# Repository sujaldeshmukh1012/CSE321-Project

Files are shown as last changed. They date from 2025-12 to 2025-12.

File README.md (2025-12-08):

<div id="top">

<!-- HEADER STYLE: CLASSIC -->
<div align="center">

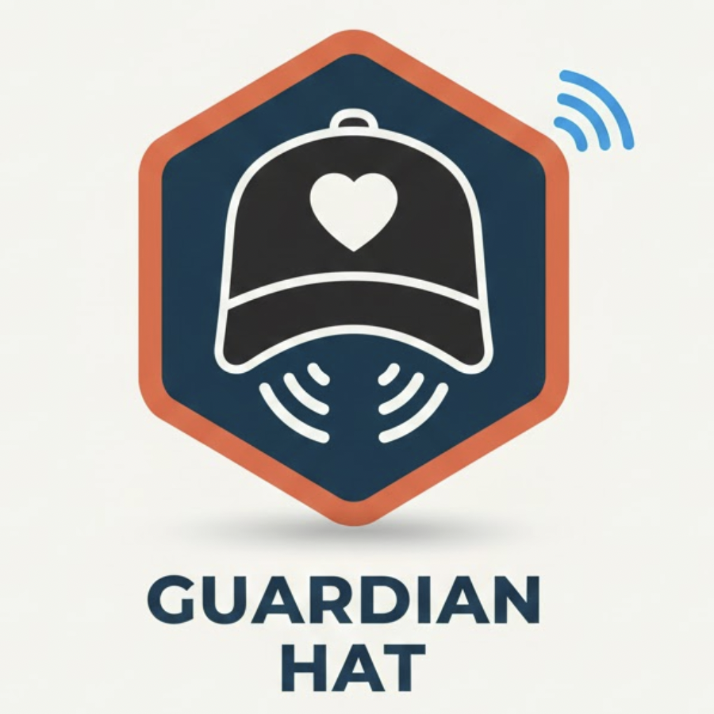
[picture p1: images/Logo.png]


# GuardianHAT

<em>Real-Time Embedded System for GPS Tracking and Environmental Monitoring</em>

<!-- BADGES -->






<em>Built with the tools and technologies:</em>

**C/C++ • ESP32-CAM • Arduino Nano • FreeRTOS • PlatformIO • KiCad PCB Design**

</div>
<br>

---

## Table of Contents

- [Overview](#overview)
- [Features](#features)
- [Hardware Components](#hardware-components)
- [PCB Design](#pcb-design)
  - [PCB Images](#pcb-images)
  - [Design Process](#design-process)
  - [Bill of Materials](#bill-of-materials)
- [Project Structure](#project-structure)
- [Getting Started](#getting-started)
  - [Prerequisites](#prerequisites)
  - [Installation](#installation)
  - [Usage](#usage)
  - [Testing](#testing)
- [System Architecture](#system-architecture)
- [Implimentation](#implimentation)
- [Contributing](#contributing)
- [License](#license)
- [Author](#author)
- [Acknowledgments](#acknowledgments)

---

## Overview

GuardianHAT is a comprehensive embedded systems solution that integrates GPS tracking, environmental sensing, and real-time monitoring capabilities. The project features two main components: an ESP32-CAM based system for camera functionality and location tracking, and an Arduino Nano RTOS implementation for sensor data processing with FreeRTOS task management.

The system includes a custom-designed PCB (Caretaker Board) that integrates all components for a professional, production-ready embedded solution.

**Key Highlights:**
- Real-time GPS satellite tracking and location monitoring
- Environmental sensing with MPU6050 (accelerometer/gyroscope)
- Distance measurement using VL53L0X ToF sensor
- OLED display (SSD1306) for real-time data visualization
- Custom PCB design with professional manufacturing files
- Multi-threaded RTOS implementation for concurrent task execution

---

## Features

### Core Functionality
- **GPS Tracking**: Real-time satellite position tracking with TinyGPS++ library
- **Motion Detection**: 6-axis motion sensing using MPU6050 (accelerometer + gyroscope)
- **Distance Measurement**: Precise ranging with VL53L0X Time-of-Flight sensor
- **Visual Display**: 128x64 OLED display for live sensor data and status information
- **Camera Module**: ESP32-CAM integration for image capture and processing
- **Real-Time OS**: FreeRTOS implementation for efficient task scheduling and resource management

### Technical Features
- Multi-tasking architecture with independent sensor polling tasks
- I2C and SPI communication protocols
- Low-power design optimizations
- Interrupt-driven button and buzzer control
- Hardware abstraction for easy sensor integration
- Professional PCB with proper power regulation and signal integrity

---

## Hardware Components

| Component | Model | Interface | Purpose |
|---|---|---|---|
| **Microcontroller** | ESP32-S3 (CAM) | - | Main processing unit with WiFi/BT |
| **Microcontroller** | Arduino Nano Every | - | RTOS sensor controller |
| **GPS Module** | NEO-6M | UART | Location tracking |
| **IMU Sensor** | MPU6050 | I2C | Motion and orientation |
| **Distance Sensor** | VL53L0X | I2C | Time-of-Flight ranging |
| **Display** | SSD1306 OLED | I2C | 128x64 visual feedback |
| **Camera** | OV2640 | - | Image capture |
| **Feedback** | Buzzer, LED| GPIO| User feedback|
| **Actuators** | Servos | PWM | Control |

---

## PCB Design

### PCB Images

The custom Caretaker PCB was designed in KiCad to integrate all system components on a single board.

<div style="display:flex;align-items:center;justify-content:space-between;" > 
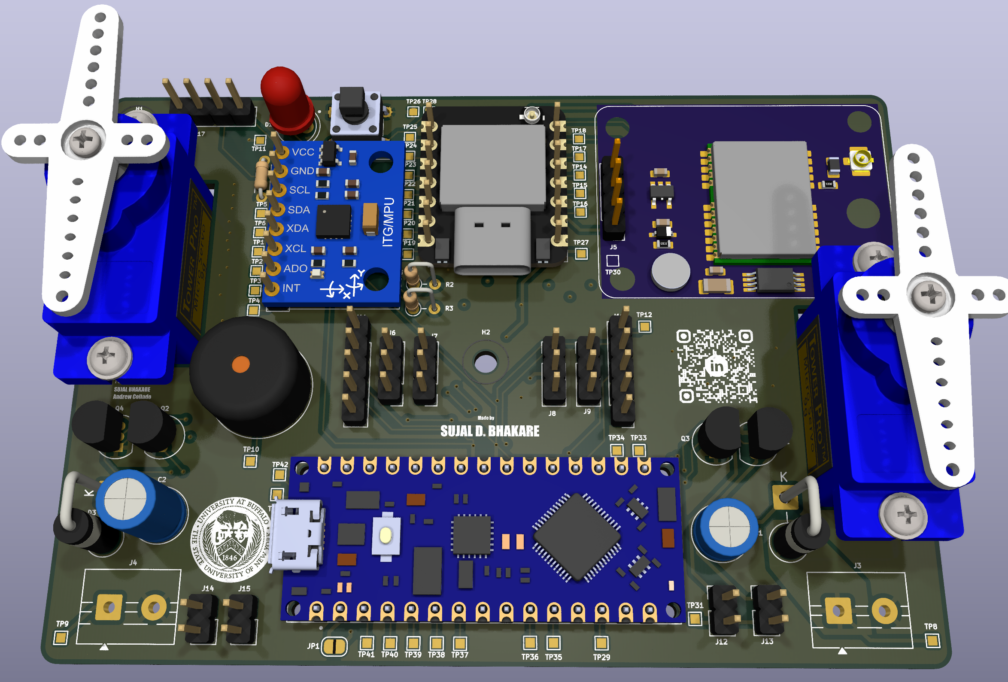
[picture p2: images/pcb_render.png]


</div>
<div style="display:flex;align-items:center;justify-content:space-between;" > 
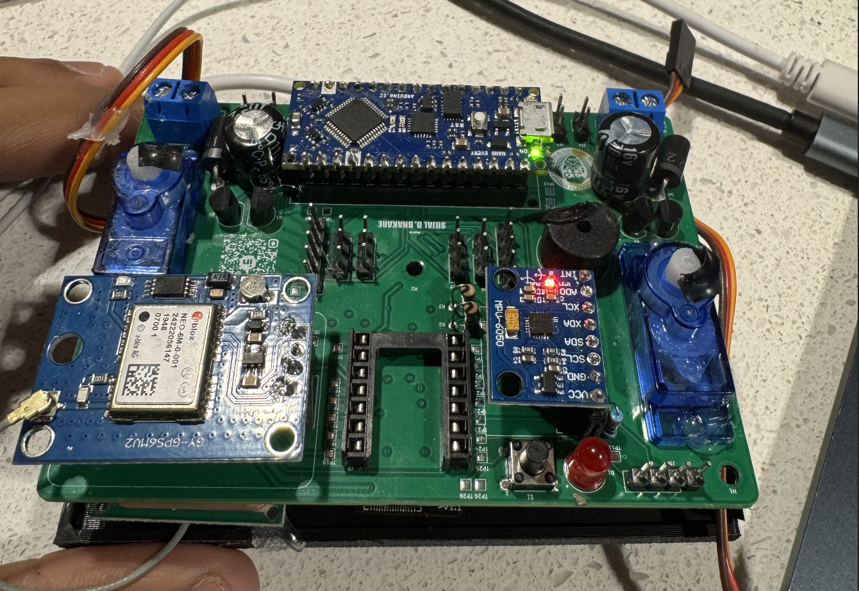
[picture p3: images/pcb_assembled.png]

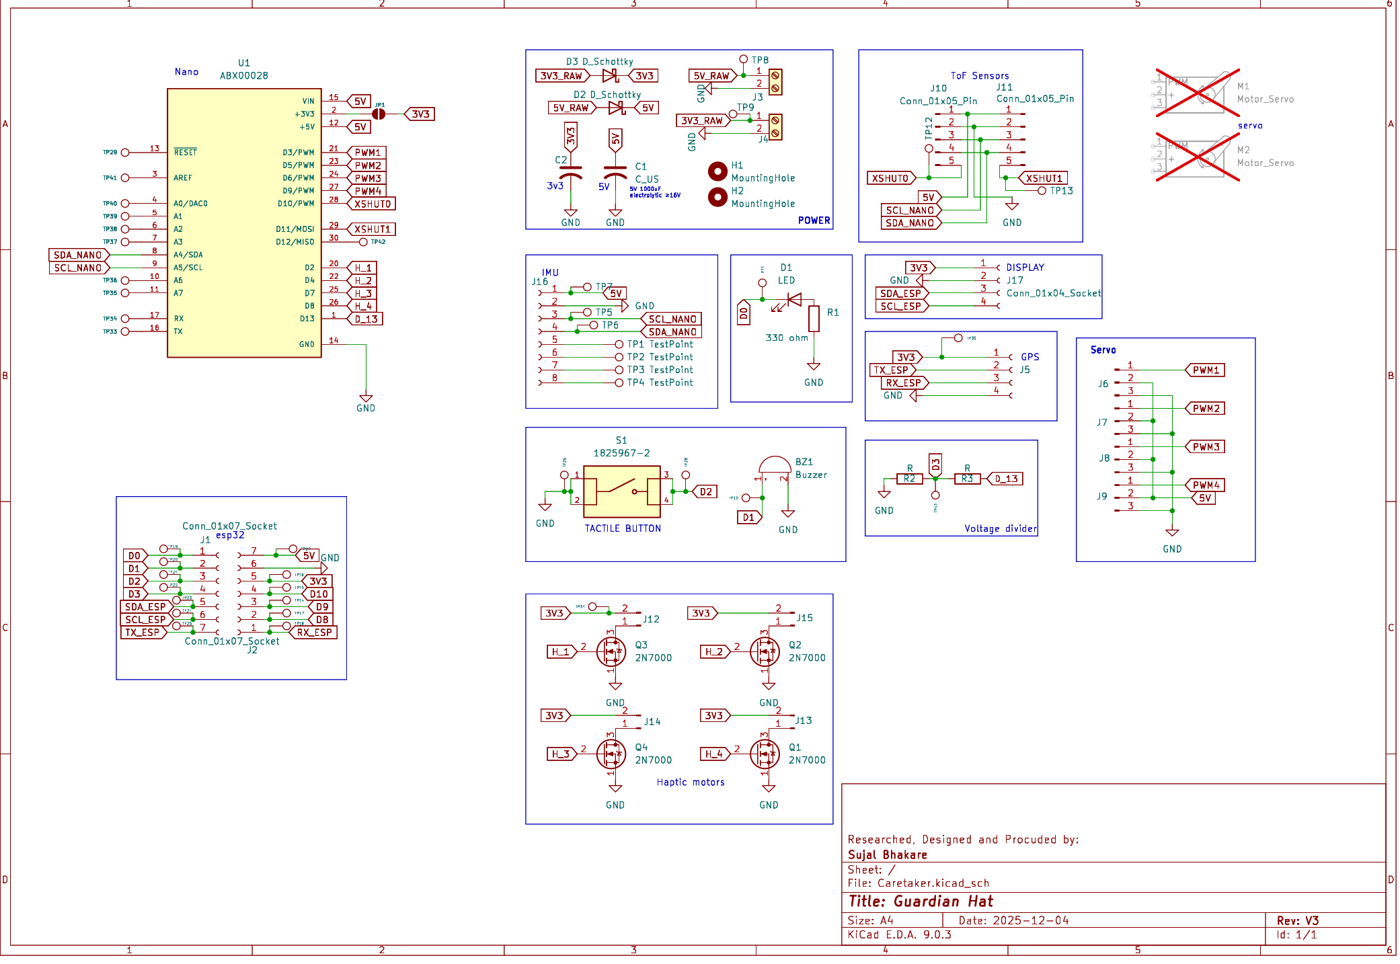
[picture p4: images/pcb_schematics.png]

</div>

### Design Process

**Tools Used:**
- **KiCad 6.0+**: Schematic capture and PCB layout
- **Component Libraries**: Custom footprints for Adafruit modules and sensors

**Manufacturing Files** (Generated Gerbers):
- `Caretaker-F_Cu.gbr` - Front copper layer
- `Caretaker-B_Cu.gbr` - Back copper layer
- `Caretaker-F_Mask.gbr` - Front soldermask
- `Caretaker-B_Mask.gbr` - Back soldermask
- `Caretaker-F_Paste.gbr` - Front paste layer (for stencil)
- `Caretaker-B_Paste.gbr` - Back paste layer
- `Caretaker-F_Silkscreen.gbr` - Front silkscreen
- `Caretaker-B_Silkscreen.gbr` - Back silkscreen
- `Caretaker-Edge_Cuts.gbr` - Board outline
- `Caretaker-job.gbrjob` - Gerber job file

**PCB Specifications:**
- **Layers**: 2-layer PCB
- **Dimensions**: 99mm x 70mm
- **Thickness**: 1.6mm (standard)
- **Copper Weight**: 1 oz (35 μm)
- **Surface Finish**: HASL

**Design Considerations:**
- Proper power plane separation for analog/digital circuits
- I2C pull-up resistors on SDA/SCL lines
- Decoupling capacitors near power pins
- Ground plane for noise reduction
- Clear component labeling on silkscreen

### Bill of Materials

Complete the quantities and part numbers based on your actual design:

| Qty | Value | Package | Description | Manufacturer Part # | Notes |
|-----|---|---|---|---|---|
| 1  | ESP32-S3 | Module | Main MCU with WiFi/BT | ESP32-S3-WROOM-1 | Seeed XIAO ESP32S3 |
| 1  | Arduino Nano | Module | RTOS Controller | ABX00028 | Arduino Nano Every |
| 1  | NEO-6M | Module | GPS Module | NEO-6M | U-blox GPS |
| 1  | MPU6050 | Module | 6-axis IMU | GY-521 | Accelerometer + Gyro |
| 1  | VL53L0X | Module | ToF Distance Sensor | - | Adafruit breakout |
| 1  | SSD1306 | Module | OLED Display | - | 128x64 I2C display |
| 1  | OV2640 | Module | Camera Module | - | ESP32-CAM compatible |
| 4  | Servo | SG90 | Micro Servo 9g | SG90 | Tower Pro |
| 1  | Buzzer | THT | Active/Passive Buzzer | - | 5V buzzer |
| 2 | LED | THT | Status Indicators | - | Red/Green |
| 2 | Resistor 4.7kΩ | THT | I2C Pull-up Resistors | - | 1% tolerance |
| 4 | Resistor 330Ω | THT | LED Current Limiting | - | - |
| 1 | Push Button | THT | User Input | 1825967-2 | Tactile switch |
| 4 | Capacitor 0.1µF | THT | Decoupling Capacitors | - | Ceramic, X7R |
| 2 | Capacitor 470µF | THT | Bulk Capacitors | - | Ceramic, X7R |
| 1 | Header | 2.54mm | UART/Debug | - | 4-pin header |
| 3 | Header | 2.54mm | I2C Expansion | - | 4-pin headers |

**Total Estimated Cost**: $50.00

**Suggested Suppliers:**
- DigiKey
- Mouser Electronics  
- Adafruit
- SparkFun
- Amazon (for modules)
- JLCPCB (for pcb fabrication)

---

## Project Structure

```sh
└── GuardianHAT/
    ├── ESP32_CAM/                    # ESP32-CAM module firmware
    │   ├── platformio.ini            # PlatformIO configuration
    │   ├── src/
    │   │   └── main.cpp              # Main ESP32 application
    │   ├── testing_code/             # Individual component tests
    │   │   ├── GPS.cpp               # GPS module testing
    │   │   ├── display.cpp           # OLED display testing
    │   │   └── buzzer_button_led.cpp # I/O peripheral tests
    │   └── lib/                      # External libraries
    │
    ├── NANO_RTOS/                    # Arduino Nano with FreeRTOS
    │   ├── platformio.ini            # PlatformIO configuration
    │   ├── src/
    │   │   └── main.cpp              # FreeRTOS task implementation
    │   └── lib/                      # RTOS and sensor libraries
    │
    ├── PCB_Design/                   # KiCad PCB project
    │   ├── Caretaker.kicad_pro       # KiCad project file
    │   ├── Caretaker.kicad_sch       # Schematic file
    │   ├── Caretaker.kicad_pcb       # PCB layout file
    │   ├── Library/                  # Custom component libraries
    │   │   ├── symbols/              # Custom schematic symbols
    │   │   └── footprints/           # Custom PCB footprints
    │   ├── Production/               # Manufacturing files (Gerbers)
    │      └── *.gbr                 # Gerber files for fab house
    │
    ├── LICENSE                       # Project license
    └── README.md                     # This file
```

---

## Getting Started

### Prerequisites

**Software Requirements:**
- **PlatformIO**: IDE extension for VS Code or CLI
- **Python 3.7+**: For PlatformIO installation
- **Git**: For version control
- **KiCad 7.0+**: For PCB design viewing/editing (optional)

**Hardware Requirements:**
- ESP32-S3 development board (Seeed XIAO ESP32S3 or similar)
- Arduino Nano Every
- USB-C cable for ESP32
- Micro-USB cable for Arduino Nano
- All sensors and components from BOM

### Installation

1. **Clone the repository:**

```sh
git clone https://github.com/sujaldeshmukh1012/GuardianHAT.git
cd GuardianHAT
```

2. **Install PlatformIO:**

```sh
# Install PlatformIO Core (CLI)
pip install platformio

# Or install VS Code + PlatformIO IDE extension
code --install-extension platformio.platformio-ide
```

3. **Install project dependencies:**

PlatformIO will automatically install dependencies defined in `platformio.ini` when you build the project.

```sh
# For ESP32-CAM module
cd ESP32_CAM
pio lib install

# For NANO RTOS module
cd ../NANO_RTOS
pio lib install
```

### Usage

**Build and Upload ESP32-CAM Firmware:**

```sh
cd ESP32_CAM
pio run --target upload
pio device monitor  # View serial output
```

**Build and Upload Arduino Nano Firmware:**

```sh
cd NANO_RTOS
pio run --target upload
pio device monitor  # View serial output
```

**Serial Monitor Settings:**
- Baud Rate: 115200
- Line Ending: Newline

**Expected Output:**
```
[GPS] Satellites: 8, Location: 42.9634° N, 78.7384° W
[MPU6050] Accel: X=0.02g Y=0.98g Z=0.05g
[VL53L0X] Distance: 245mm
[Display] Status: OK
```

### Testing

The project includes individual component test files in `ESP32_CAM/testing_code/`:

**Test GPS Module:**
```sh
# Edit platformio.ini to set src_dir to testing_code
# Then uncomment the GPS.cpp file
pio run --target upload
```

**Test Display:**
```sh
# Use display.cpp as main source
pio run --target upload
```

**Test I/O Peripherals:**
```sh
# Use buzzer_button_led.cpp as main source
pio run --target upload
```

**Run All Tests:**
```sh
# Both projects include test directories
cd NANO_RTOS
pio test

cd ../ESP32_CAM
pio test
```

---

## System Architecture

### ESP32-CAM Module
- **Main Tasks**: Camera capture, WiFi connectivity, GPS data logging
- **Sensors**: GPS (NEO-6M), Camera (OV2640)
- **Communication**: WiFi for data transmission

### Arduino Nano RTOS Module
- **Main Tasks**: Sensor polling, OLED display updates, real-time processing
- **RTOS Tasks**:
  - Task 1: MPU6050 data acquisition (100Hz)
  - Task 2: VL53L0X distance measurement (50Hz)
  - Task 3: Display update task (10Hz)
  - Task 4: User input handling (interrupt-based)
- **Communication**: I2C for sensors, SPI for potential expansions

### Communication Protocol
The two modules communicate via UART to share sensor data and coordinate actions.

---
## Implimentation

The project was designed and demoed for the CSE 321 class project at University at Buffalo.

I have used external power and step-down converters to provide ample power to the 5v and 3v3 systems.

**The class has a constraint to use from the shelf Arduino products like Nano, Uno, Mega. So the project used the full dev boards instead of a much compact custom board using only what is needed.**

<div style="display:flex;align-items:center;justify-content:space-between;" > 
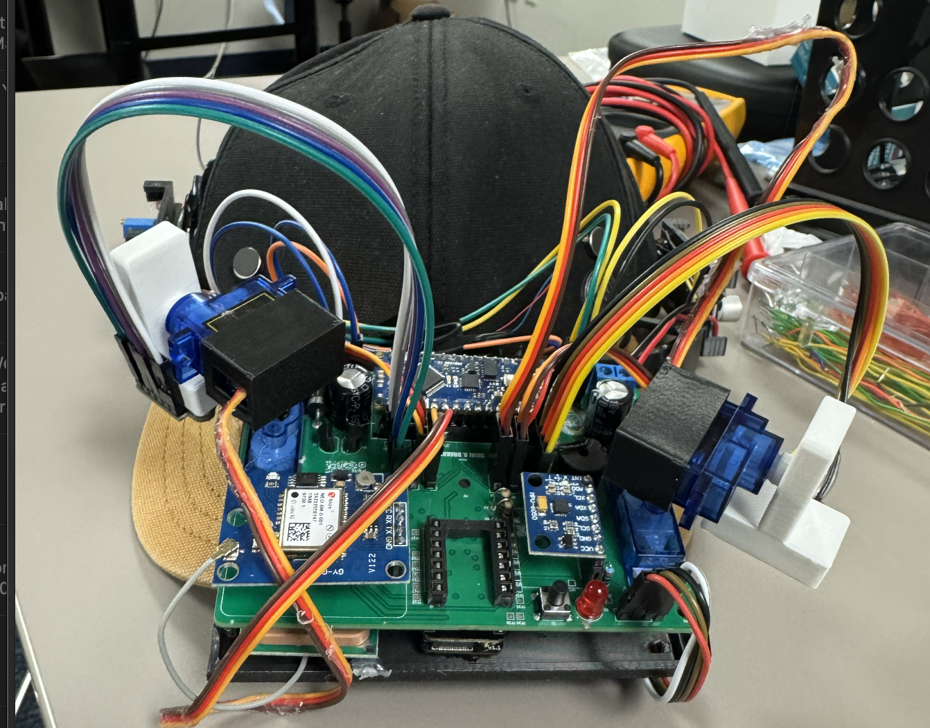
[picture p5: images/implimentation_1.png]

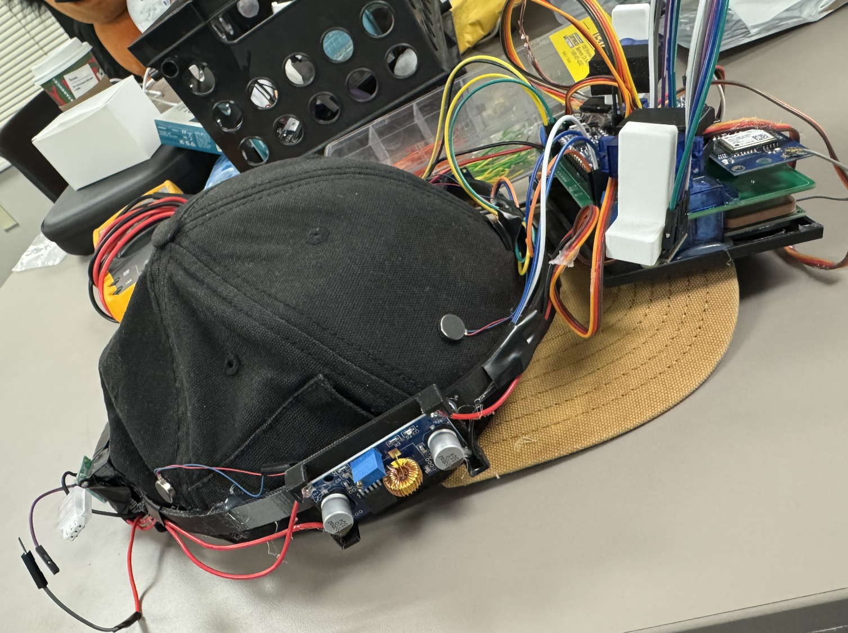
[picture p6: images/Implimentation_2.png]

</div>

<br>
<div style="display:flex;align-items:center;justify-content:center;">
  <a href="https://www.youtube.com/shorts/iIOURSS3Xgc" style="text-decoration:none;">
      
  </a>
</div>

---

## Author

<div align="center">

Your Name

### Sujal Bhakare

**Systems Engineer | Computer Science Student**






</div>
---

## Acknowledgments

- **Adafruit Industries**: For excellent sensor libraries and breakout boards
- **Arduino Community**: For FreeRTOS port and examples
- **Espressif Systems**: For ESP32 development framework
- **KiCad EDA**: For open-source PCB design software
- **TinyGPS++**: Mikal Hart's GPS parsing library
- **Course Staff**: CSE321 instructor and TAs
- **My Amazing Teammate:** Andrew Collado [LinkedIn](https://www.linkedin.com/in/andrew-collado/)

### References
- [ESP32-CAM Documentation](https://docs.espressif.com/)
- [FreeRTOS Documentation](https://www.freertos.org/Documentation/RTOS_book.html)
- [KiCad Documentation](https://docs.kicad.org/)
- [PlatformIO Documentation](https://docs.platformio.org/)

---

<div align="center">

**[⬆ Back to Top](#top)**

Made with ❤️ by [Andrew Collado]((https://www.linkedin.com/in/andrew-collado/)) & [Sujal Bhakare](https://sujalbhakare.com)

</div>

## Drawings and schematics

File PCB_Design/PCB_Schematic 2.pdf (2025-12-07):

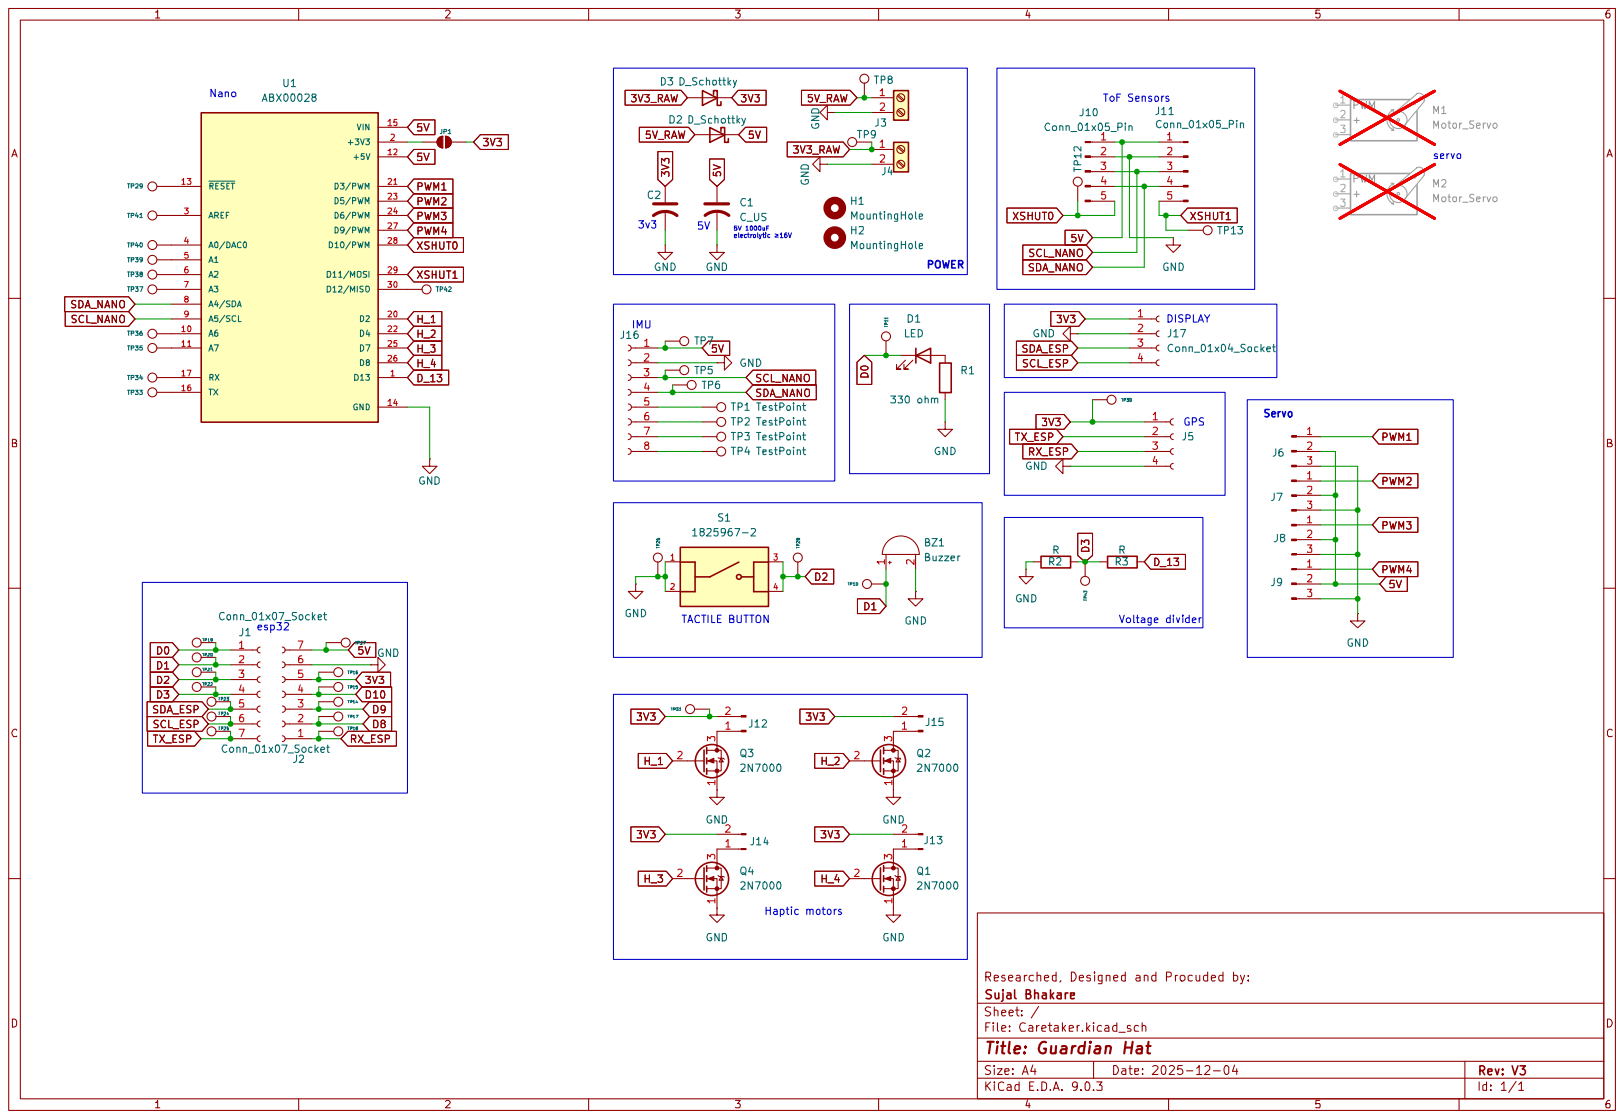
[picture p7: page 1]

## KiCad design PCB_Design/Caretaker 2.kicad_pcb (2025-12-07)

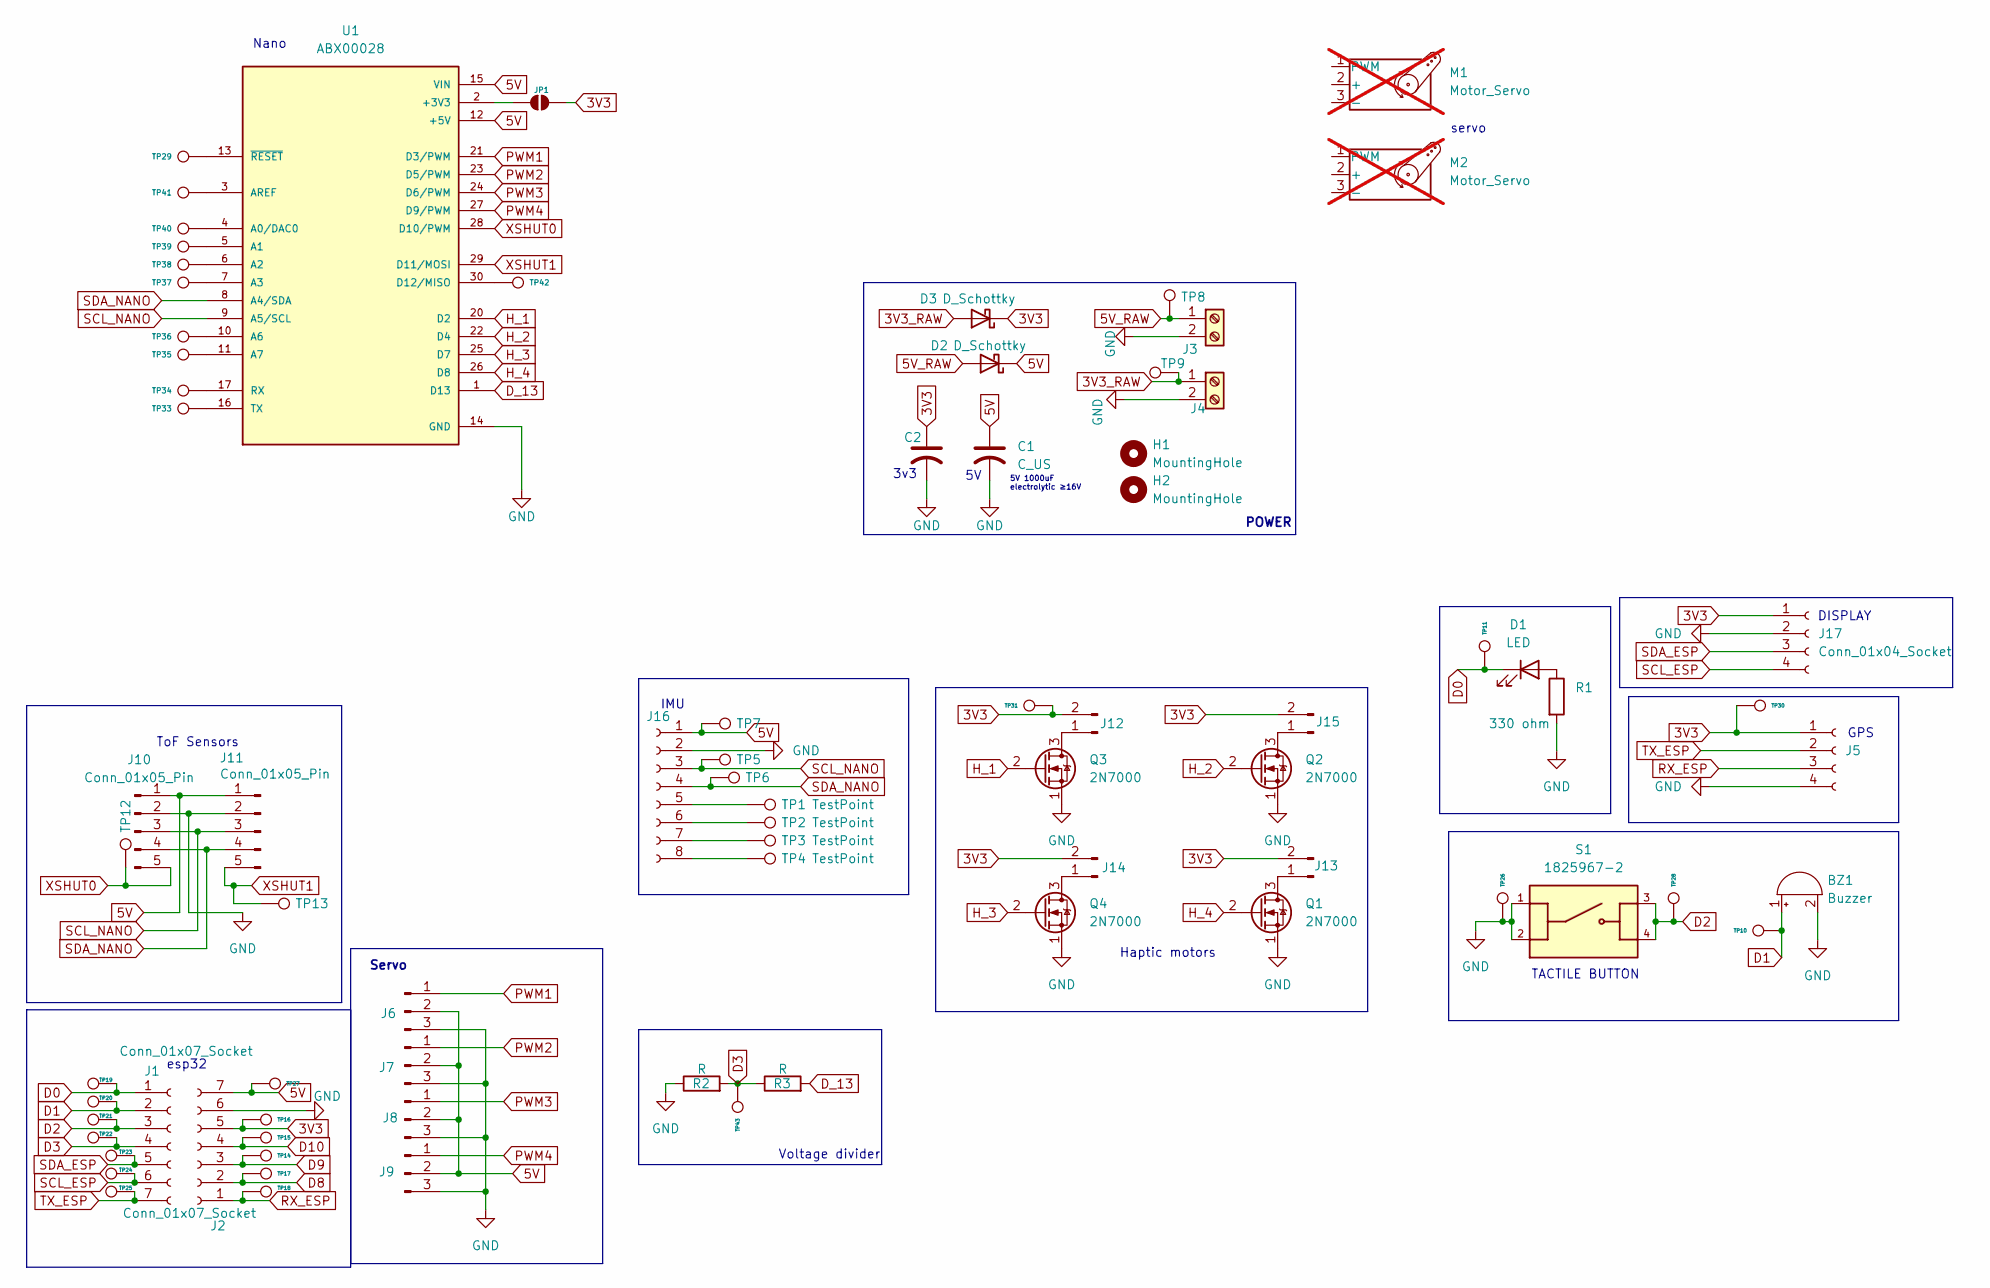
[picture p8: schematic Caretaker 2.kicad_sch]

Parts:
BZ1: Buzzer; Buzzer_12x9.5RM7.6
C1: C_US; C_Radial_D6.3mm_H5.0mm_P2.50mm
C2: C_US; C_Radial_D6.3mm_H11.0mm_P2.50mm
D1: LED; LED_D5.0mm
D2, D3: D_Schottky; D_5W_P5.08mm_Vertical_KathodeUp
H1, H2: MountingHole; MountingHole_2.7mm_M2.5
J1, J2: Conn_01x07_Socket; PinHeader_1x07_P2.54mm_Vertical
J3, J4: Screw_Terminal_01x02; TerminalBlock_MaiXu_MX126-5.0-02P_1x02_P5.00mm
J5, J17: Conn_01x04_Socket; PinHeader_1x04_P2.54mm_Vertical
J6, J7, J8, J9: Conn_01x03_Pin; PinHeader_1x03_P2.54mm_Vertical
J10, J11: Conn_01x05_Pin; PinHeader_1x05_P2.54mm_Vertical
J12, J13, J14, J15: Conn_01x02_Pin; PinHeader_1x02_P2.54mm_Vertical
J16: Conn_01x08_Socket; PinHeader_1x08_P2.54mm_Vertical
JP1: SolderJumper_2_Open; SolderJumper-2_P1.3mm_Open_RoundedPad1.0x1.5mm
M1, M2: Motor_Servo; MountingHole_8.4mm_M8_Pad_TopOnly; not fitted
Q1, Q2, Q3, Q4: 2N7000; TO-92_Inline
R1: 330 ohm; R_Axial_DIN0204_L3.6mm_D1.6mm_P5.08mm_Horizontal
R2, R3: R; R_Axial_DIN0204_L3.6mm_D1.6mm_P2.54mm_Vertical
S1: 1825967-2; SW_1825967-2
TP1, TP2, TP3, TP4, TP5, TP6, TP7, TP8, TP9, TP10, TP11, TP12, TP13, TP14, TP15, TP16, TP17, TP18, TP19, TP20, TP21, TP22, TP23, TP24, TP25, TP26, TP27, TP28, TP29, TP30, TP31, TP33, TP34, TP35, TP36, TP37, TP38, TP39, TP40, TP41, TP42, TP43: TestPoint; TestPoint_Pad_1.0x1.0mm
U1: ABX00028; MODULE_ABX00028; PARTREV 6-11-19

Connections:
3V3: C2.1, D3.1 (K), J2.5, J5.1, J12.2, J13.2, J14.2, J15.2, J17.1, JP1.2 (B), TP16.1, TP30.1, TP31.1
3V3_RAW: D3.2 (A), J4.1, TP9.1
5V: C1.1, D2.1 (K), J2.7, J6.2, J7.2, J8.2, J9.2, J10.1, J11.1, J16.1, TP7.1, TP27.1, U1.12 (+5V), U1.15 (VIN)
5V_RAW: D2.2 (A), J3.1, TP8.1
D0: D1.1 (K), J1.1, TP11.1, TP19.1
D1: BZ1.1 (+), J1.2, TP10.1, TP20.1
D2: J1.3, S1.3, S1.4, TP21.1, TP28.1
D3: J1.4, R2.2, R3.1, TP22.1, TP43.1
D8: J2.2, TP17.1
D9: J2.3, TP14.1
D10: J2.4, TP15.1
D_13: R3.2, U1.1 (D13)
GND: BZ1.2 (-), C1.2, C2.2, J2.6, J3.2, J4.2, J5.4, J6.3, J7.3, J8.3, J9.3, J10.2, J11.2, J16.2, J17.2, Q1.1 (S), Q2.1 (S), Q3.1 (S), Q4.1 (S), R1.2, R2.1, S1.1, S1.2, TP26.1, U1.14 (GND), U1.19 (GND)
H_1: Q3.2 (G), U1.20 (D2)
H_2: Q2.2 (G), U1.22 (D4)
H_3: Q4.2 (G), U1.25 (D7)
H_4: Q1.2 (G), U1.26 (D8)
unnamed: D1.2 (A), R1.1
unnamed: J12.1, Q3.3 (D)
unnamed: J13.1, Q1.3 (D)
unnamed: J14.1, Q4.3 (D)
unnamed: J15.1, Q2.3 (D)
unnamed: J16.5, TP1.1
unnamed: J16.6, TP2.1
unnamed: J16.7, TP3.1
unnamed: J16.8, TP4.1
unnamed: JP1.1 (A), U1.2 (+3V3)
unnamed: TP29.1, U1.13 (~RESET), U1.18 (~RESET)
unnamed: TP40.1, U1.4 (A0/DAC0)
unnamed: TP39.1, U1.5 (A1)
unnamed: TP38.1, U1.6 (A2)
unnamed: TP37.1, U1.7 (A3)
unnamed: TP36.1, U1.10 (A6)
unnamed: TP35.1, U1.11 (A7)
unnamed: TP41.1, U1.3 (AREF)
unnamed: TP42.1, U1.30 (D12/MISO)
unnamed: TP34.1, U1.17 (RX)
unnamed: TP33.1, U1.16 (TX)
PWM1: J6.1, U1.21 (D3/PWM)
PWM2: J7.1, U1.23 (D5/PWM)
PWM3: J8.1, U1.24 (D6/PWM)
PWM4: J9.1, U1.27 (D9/PWM)
RX_ESP: J2.1, J5.3, TP18.1
SCL_ESP: J1.6, J17.4, TP24.1
SCL_NANO: J10.3, J11.3, J16.3, TP5.1, U1.9 (A5/SCL)
SDA_ESP: J1.5, J17.3, TP23.1
SDA_NANO: J10.4, J11.4, J16.4, TP6.1, U1.8 (A4/SDA)
TX_ESP: J1.7, J5.2, TP25.1
XSHUT0: J10.5, TP12.1, U1.28 (D10/PWM)
XSHUT1: J11.5, TP13.1, U1.29 (D11/MOSI)

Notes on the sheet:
ToF Sensors
GPS
DISPLAY
POWER
TACTILE BUTTON
Nano
Haptic motors
esp32
Servo
servo
5V 1000uF electrolytic ≥16V
3v3
Voltage divider
IMU

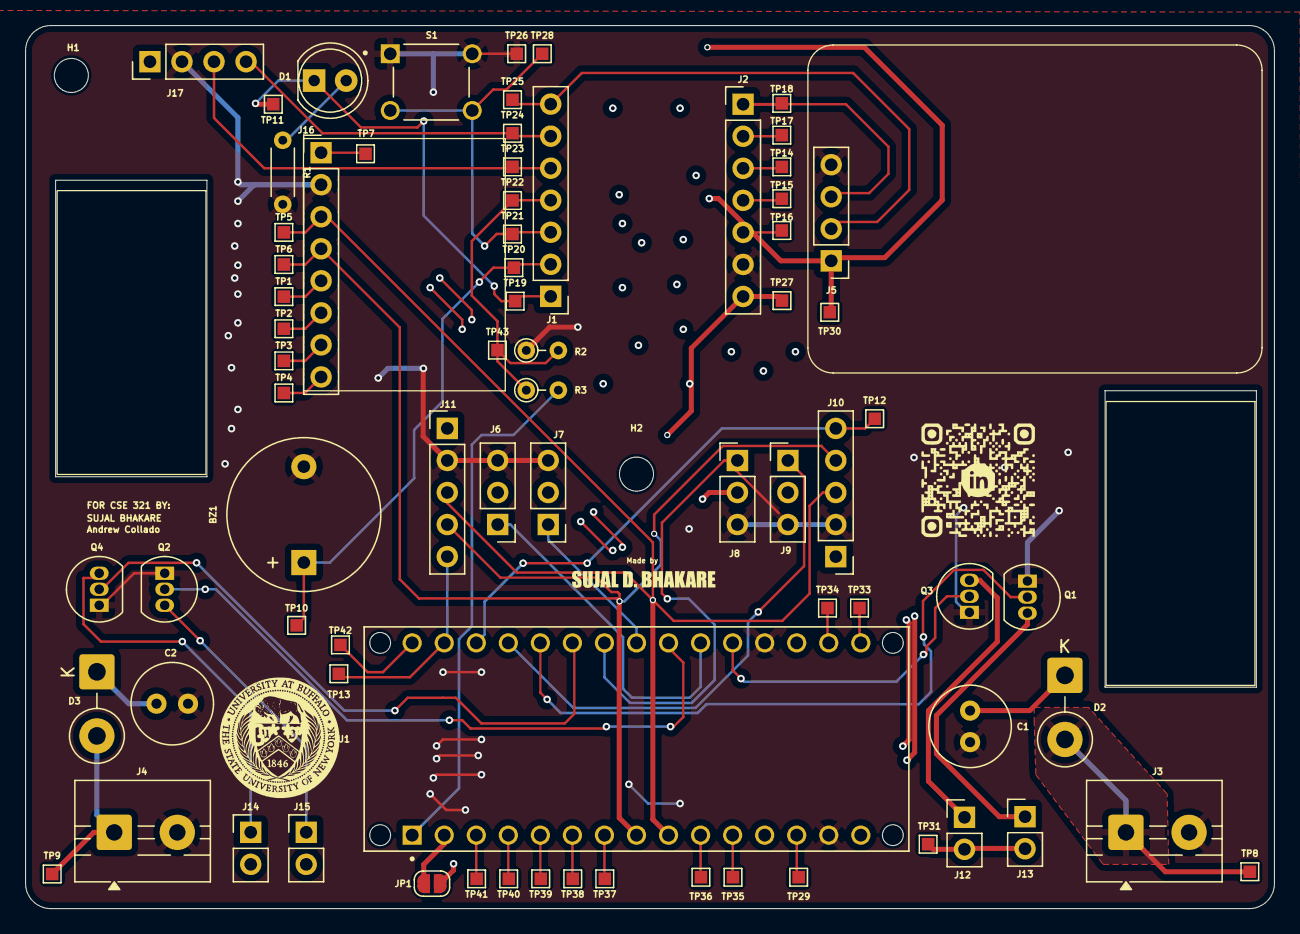
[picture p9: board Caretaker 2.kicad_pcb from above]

Board: 2 copper layers, 99.0 x 70.0 mm, 79 parts (0 on the bottom side), 50 nets.

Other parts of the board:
M1#2: Motor_Servo; MountingHole_8.4mm_M8_Pad_TopOnly

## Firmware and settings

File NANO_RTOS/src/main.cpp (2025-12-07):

#include <Arduino.h>
#include <Wire.h>
#include <Servo.h>
#include <Adafruit_VL53L0X.h>

// Nano Every digital pins 10, 11, 12, 13 are used for Servo control.
#define SERVO_CH_H_RIG1_PIN  3
#define SERVO_CH_H_RIG2_PIN  9 
#define SERVO_CH_V_RIG1_PIN  5 
#define SERVO_CH_V_RIG2_PIN  6 

// for changing the hardware i2c address of the individual ToF Sensor
#define SENSOR_1_XSHUT       10
#define SENSOR_2_XSHUT       11

// --- HAPTIC PINS ---
#define HAPTIC_FRONT_LEFT    7
#define HAPTIC_BACK_LEFT     2
#define HAPTIC_FRONT_RIGHT   4
#define HAPTIC_BACK_RIGHT    8

// I2C Address for Sensor 1 (default for S2 will be 0x29)
#define SENSOR_1_NEW_ADDRESS 0x30


// --- THRESHOLDS AND TIMING ---
#define DETECTION_THRESHOLD_MM 200      // Distance in mm to trigger haptic feedback
#define SERVO_MIN_US        500          // Min pulse width for servo (fully counter-clockwise)
#define SERVO_MAX_US        2500        // Max pulse width for servo (fully clockwise)
#define SWEEP_PERIOD_US     3000000UL   /// 3 seconds period for one full sweep (up and down)
#define LOOP_DELAY_MS       5           // I2C throttling delay to prevent bus contention

#define SYSTEM_RUN_TIME_MS   20000UL   //- System halts after 20 seconds (20,000ms)

#define SERVO_RANGE_H_DEG    90.0f     // New horizontal sweep range (Reduced to 90 degrees)
#define SERVO_MIN_H_DEG      45.0f     // (180 - 90) / 2 = 45.0 to start the sweep

#define SERVO_RANGE_V_DEG    45.0f     // New vertical sweep range
#define SERVO_MIN_V_DEG      22.5f     // (90 - 45) / 2 =22.5 to start the sweep


Adafruit_VL53L0X lox1 = Adafruit_VL53L0X();
Adafruit_VL53L0X lox2 = Adafruit_VL53L0X();

Servo servo_h_rig1;
Servo servo_h_rig2;
Servo servo_v_rig1;
Servo servo_v_rig2;

unsigned long startTime = 0; 

static void writeServoUs(Servo& servo, float angleDeg, float maxDeg) {
  if (angleDeg < 0.0f) angleDeg = 0.0f;
  if (angleDeg > maxDeg) angleDeg = maxDeg;
  float ratio = angleDeg / maxDeg;
  const float pulse_range = (float)(SERVO_MAX_US - SERVO_MIN_US);
  float us_float = SERVO_MIN_US + (ratio * pulse_range);
  servo.writeMicroseconds((uint16_t)us_float);
}

void initSensor(Adafruit_VL53L0X &lox, int xshutPin, uint8_t newAddr, bool firstSensor) {
  pinMode(xshutPin, OUTPUT);
  digitalWrite(xshutPin, LOW);
  delay(10);
  digitalWrite(xshutPin, HIGH);
  delay(10); // Give time for boot

  if (!lox.begin()) {
    Serial.print(F("Failed to boot sensor on XSHUT D"));
    Serial.println(xshutPin);
    while(1) {
      digitalWrite(LED_BUILTIN, HIGH);
      delay(100);
      digitalWrite(LED_BUILTIN, LOW);
      delay(100);
    }
  }

  if (firstSensor) {
    lox.setAddress(newAddr);
    Serial.print(F("Sensor 1 (Left) initialized and address changed to 0x"));
    Serial.println(newAddr, HEX);
  } else {
    Serial.println(F("Sensor 2 (Right) initialized and kept default 0x29."));
  }
}

void setup() {
  Serial.begin(115200);
  while (!Serial);
  Serial.println(F("Starting Nano Every System Initialization..."));
  pinMode(HAPTIC_FRONT_LEFT, OUTPUT);
  pinMode(HAPTIC_BACK_LEFT, OUTPUT);
  pinMode(HAPTIC_FRONT_RIGHT, OUTPUT);
  pinMode(HAPTIC_BACK_RIGHT, OUTPUT);
  pinMode(LED_BUILTIN, OUTPUT);
  digitalWrite(HAPTIC_FRONT_LEFT, LOW);
  digitalWrite(HAPTIC_BACK_LEFT, LOW);
  digitalWrite(HAPTIC_FRONT_RIGHT, LOW);
  digitalWrite(HAPTIC_BACK_RIGHT, LOW);
  servo_h_rig1.attach(SERVO_CH_H_RIG1_PIN, SERVO_MIN_US, SERVO_MAX_US);
  servo_h_rig2.attach(SERVO_CH_H_RIG2_PIN, SERVO_MIN_US, SERVO_MAX_US);
  servo_v_rig1.attach(SERVO_CH_V_RIG1_PIN, SERVO_MIN_US, SERVO_MAX_US);
  servo_v_rig2.attach(SERVO_CH_V_RIG2_PIN, SERVO_MIN_US, SERVO_MAX_US);
  writeServoUs(servo_h_rig1, 90.0f, 180.0f); // Center horizontal
  writeServoUs(servo_h_rig2, 90.0f, 180.0f); // Center horizontal
  writeServoUs(servo_v_rig1, 45.0f, 90.0f);  // Middle vertical sweep range
  writeServoUs(servo_v_rig2, 45.0f, 90.0f);  // Middle vertical sweep range

  Serial.println(F("Servos initialized for Nano Every."));
  Wire.begin();
  Wire.setClock(400000UL);    // Fast-mode I2C for faster communication
  pinMode(SENSOR_1_XSHUT, OUTPUT);
  pinMode(SENSOR_2_XSHUT, OUTPUT);
  digitalWrite(SENSOR_1_XSHUT, LOW);
  digitalWrite(SENSOR_2_XSHUT, LOW);

  initSensor(lox1, SENSOR_1_XSHUT, SENSOR_1_NEW_ADDRESS, true);
  initSensor(lox2, SENSOR_2_XSHUT, 0x29, false); // S2 keeps default 0x29

  startTime = millis(); 

  Serial.println(F("System ready. Starting loop..."));
}

/*********** Loop ***********/
void loop() {
  // 1. Calculate the sweep factor (0.0 to 1.0 back to 0.0) based on time
  uint32_t t_us = micros() % SWEEP_PERIOD_US;
  float half_period_us = SWEEP_PERIOD_US / 2.0f;
  float sweep_factor;

  if (t_us < half_period_us) {
    // Phase 1: 0 to 1.0
    sweep_factor = (float)t_us / half_period_us;
  } else {
    // Phase 2: 1.0 back to 0.0
    sweep_factor = 1.0f - (((float)t_us - half_period_us) / half_period_us);
  }

  float h_angle = SERVO_MIN_H_DEG + (sweep_factor * SERVO_RANGE_H_DEG);
  float v_angle = SERVO_MIN_V_DEG + (sweep_factor * SERVO_RANGE_V_DEG);
  writeServoUs(servo_h_rig1, h_angle, 180.0f);
  writeServoUs(servo_h_rig2, h_angle, 180.0f);
  writeServoUs(servo_v_rig1, v_angle, 90.0f);
  writeServoUs(servo_v_rig2, v_angle, 90.0f);
  VL53L0X_RangingMeasurementData_t measure1; // Left
  VL53L0X_RangingMeasurementData_t measure2; // Right
  lox1.rangingTest(&measure1, false);
  lox2.rangingTest(&measure2, false);
  bool obstacleLeft = (measure1.RangeStatus != 4 && measure1.RangeMilliMeter < DETECTION_THRESHOLD_MM);
  bool obstacleRight = (measure2.RangeStatus != 4 && measure2.RangeMilliMeter < DETECTION_THRESHOLD_MM);
  digitalWrite(HAPTIC_FRONT_LEFT, obstacleLeft ? HIGH : LOW);
  digitalWrite(HAPTIC_BACK_LEFT, obstacleLeft ? HIGH : LOW);
  digitalWrite(HAPTIC_FRONT_RIGHT, obstacleRight ? HIGH : LOW);
  digitalWrite(HAPTIC_BACK_RIGHT, obstacleRight ? HIGH : LOW);
  Serial.print(F("S1 (L): "));
  Serial.print(obstacleLeft ? measure1.RangeMilliMeter : 9999);
  Serial.print(F("mm, Haptic L: "));
  Serial.print(obstacleLeft ? F("ON") : F("OFF"));

  Serial.print(F(" | S2 (R): "));
  Serial.print(obstacleRight ? measure2.RangeMilliMeter : 9999);
  Serial.print(F("mm, Haptic R: "));
  Serial.println(obstacleRight ? F("ON") : F("OFF"));
  delay(LOOP_DELAY_MS);

  if (millis() - startTime >= SYSTEM_RUN_TIME_MS) {
    Serial.println(F("\n--- 20 SECOND RUNTIME COMPLETE. SYSTEM HALTING. ---"));
    
    writeServoUs(servo_h_rig1, 90.0f, 180.0f);
    writeServoUs(servo_h_rig2, 90.0f, 180.0f);
    writeServoUs(servo_v_rig1, 45.0f, 90.0f);
    writeServoUs(servo_v_rig2, 45.0f, 90.0f);
    
    servo_h_rig1.detach();
    servo_h_rig2.detach();
    servo_v_rig1.detach();
    servo_v_rig2.detach();

    digitalWrite(HAPTIC_FRONT_LEFT, LOW);
    digitalWrite(HAPTIC_BACK_LEFT, LOW);
    digitalWrite(HAPTIC_FRONT_RIGHT, LOW);
    digitalWrite(HAPTIC_BACK_RIGHT, LOW);

    for(int i = 0; i < 5; i++) {
      digitalWrite(LED_BUILTIN, HIGH);
      delay(100);
      digitalWrite(LED_BUILTIN, LOW);
      delay(100);
    }
    
    // Halt execution indefinitely
    while (true) {
      Serial.println(F("System Halted."));
      delay(5000); 
    }
  }
}

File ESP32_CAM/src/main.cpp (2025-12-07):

#include <WiFi.h>
#include <WebServer.h>
#include <Wire.h>
#include <Adafruit_GFX.h>
#include <Adafruit_SSD1306.h>
#include <TinyGPS++.h>
#include "esp_camera.h"

// WiFi credentials
const char* ssid = "UB_Devices";
const char* password = "goubbulls";

// Pin definitions
#define GPS_RX 43
#define GPS_TX 44
#define LED_PIN D0
#define BUZZER_PIN D1
#define BUTTON_PIN D2
#define NANO_COMM_PIN D3
#define SDA_PIN 5
#define SCL_PIN 6

// OLED Display settings
#define SCREEN_WIDTH 128
#define SCREEN_HEIGHT 64
#define OLED_RESET -1
Adafruit_SSD1306 display(SCREEN_WIDTH, SCREEN_HEIGHT, &Wire, OLED_RESET);


volatile bool nano_status=false;

void handleRoot();
void handleStream(); 
void handleSOSStatus();
void handleMap();
void handleSendMessage();
void handleButton();
void updateGPSData(); 
void handleCapture();
void updateDisplay();
void setupWebServer();
void connectWiFi();
void initCamera();
// GPS
TinyGPSPlus gps;
HardwareSerial gpsSerial(1);

// Default coordinates (if GPS unstable)
float defaultLat = 43.0017;
float defaultLng = -78.7849;

// GPS variables
float latitude = defaultLat;
float longitude = defaultLng;
int satellites = 0;
float altitude = 0;
float speed = 0;

// SOS state
bool sosActive = false;
unsigned long lastBuzzerToggle = 0;
bool buzzerState = false;

// Button handling
unsigned long lastButtonPress = 0;
unsigned long buttonPressStart = 0;
int buttonPressCount = 0;
bool buttonPressed = false;
#define DEBOUNCE_DELAY 50
#define DOUBLE_CLICK_TIME 400

// Web server
WebServer server(80);

// Display message from web
String webMessage = "";

// Camera pins for ESP32-CAM (xiao model settingd)
#define PWDN_GPIO_NUM -1
#define RESET_GPIO_NUM -1
#define XCLK_GPIO_NUM 10
#define SIOD_GPIO_NUM 40
#define SIOC_GPIO_NUM 39
#define Y9_GPIO_NUM 48
#define Y8_GPIO_NUM 11
#define Y7_GPIO_NUM 12
#define Y6_GPIO_NUM 14
#define Y5_GPIO_NUM 16
#define Y4_GPIO_NUM 18
#define Y3_GPIO_NUM 17
#define Y2_GPIO_NUM 15
#define VSYNC_GPIO_NUM 38
#define HREF_GPIO_NUM 47
#define PCLK_GPIO_NUM 13

void setup() {
  Serial.begin(115200);
  
  // Pin modes
  pinMode(LED_PIN, OUTPUT);
  pinMode(BUZZER_PIN, OUTPUT);
  pinMode(BUTTON_PIN, INPUT_PULLUP);
  pinMode(NANO_COMM_PIN, OUTPUT);
  digitalWrite(NANO_COMM_PIN, LOW);
  digitalWrite(BUZZER_PIN, LOW);
  
  // I2C for OLED
  Wire.begin(SDA_PIN, SCL_PIN);
  
  // Initialize OLED
  if(!display.begin(SSD1306_SWITCHCAPVCC, 0x3C)) {
    Serial.println(F("SSD1306 allocation failed"));
    for(;;);
  }
  display.clearDisplay();
  display.setTextSize(1);
  display.setTextColor(SSD1306_WHITE);
  display.setCursor(0,0);
  display.println("Initializing...");
  display.display();
  
  // Initialize GPS
  gpsSerial.begin(9600, SERIAL_8N1, GPS_RX, GPS_TX);
  
  // Initialize camera
  initCamera();
  
  // Connect to WiFi
  connectWiFi();
  
  // Setup web server routes
  setupWebServer();
  
  display.clearDisplay();
  display.setCursor(0,0);
  display.println("Ready!");
  display.println("IP: " + WiFi.localIP().toString());
  display.display();
  delay(2000);
}

void loop() {
  // Handle GPS data
  while (gpsSerial.available() > 0) {
    if (gps.encode(gpsSerial.read())) {
      updateGPSData();
    }
  }
  
  // Handle button presses
  handleButton();
  
  // Handle SOS buzzer
  if (sosActive) {
    unsigned long currentMillis = millis();
    if (currentMillis - lastBuzzerToggle >= 500) {
      buzzerState = !buzzerState;
      digitalWrite(BUZZER_PIN, buzzerState ? HIGH : LOW);
      lastBuzzerToggle = currentMillis;
    }
  }
  
  // Handle web server
  server.handleClient();
  
  // Update display
  updateDisplay();
  
  delay(100);
}

void initCamera() {
  camera_config_t config;
  config.ledc_channel = LEDC_CHANNEL_0;
  config.ledc_timer = LEDC_TIMER_0;
  config.pin_d0 = Y2_GPIO_NUM;
  config.pin_d1 = Y3_GPIO_NUM;
  config.pin_d2 = Y4_GPIO_NUM;
  config.pin_d3 = Y5_GPIO_NUM;
  config.pin_d4 = Y6_GPIO_NUM;
  config.pin_d5 = Y7_GPIO_NUM;
  config.pin_d6 = Y8_GPIO_NUM;
  config.pin_d7 = Y9_GPIO_NUM;
  config.pin_xclk = XCLK_GPIO_NUM;
  config.pin_pclk = PCLK_GPIO_NUM;
  config.pin_vsync = VSYNC_GPIO_NUM;
  config.pin_href = HREF_GPIO_NUM;
  config.pin_sscb_sda = SIOD_GPIO_NUM;
  config.pin_sscb_scl = SIOC_GPIO_NUM;
  config.pin_pwdn = PWDN_GPIO_NUM;
  config.pin_reset = RESET_GPIO_NUM;
  config.xclk_freq_hz = 20000000;
  config.pixel_format = PIXFORMAT_JPEG;
  
  if(psramFound()){
    config.frame_size = FRAMESIZE_UXGA;
    config.jpeg_quality = 10;
    config.fb_count = 2;
  } else {
    config.frame_size = FRAMESIZE_SVGA;
    config.jpeg_quality = 12;
    config.fb_count = 1;
  }
  
  esp_err_t err = esp_camera_init(&config);
  if (err != ESP_OK) {
    Serial.printf("Camera init failed with error 0x%x", err);
    return;
  }
}

void connectWiFi() {
  display.clearDisplay();
  display.setCursor(0,0);
  display.println("Connecting WiFi...");
  display.display();
  
  WiFi.begin(ssid, password);
  int attempts = 0;
  while (WiFi.status() != WL_CONNECTED && attempts < 20) {
    delay(500);
    Serial.print(".");
    attempts++;
  }
  
  if (WiFi.status() == WL_CONNECTED) {
    Serial.println("\nWiFi connected");
    Serial.print("IP: ");
    Serial.println(WiFi.localIP());
  } else {
    Serial.println("\nWiFi connection failed");
  }
}

void setupWebServer() {
  server.on("/", handleRoot);
  server.on("/stream", handleStream);
  server.on("/sos_status", handleSOSStatus);
  server.on("/map", handleMap);
  server.on("/send_message", HTTP_POST, handleSendMessage);
  server.on("/capture", handleCapture);
  server.begin();
  Serial.println("Web server started");
  Serial.print("Access at: http://");
  Serial.println(WiFi.localIP());
}

void handleRoot() {
  String html = "<!DOCTYPE html><html><head><title>ESP32 Tracker</title>";
  html += "<meta name='viewport' content='width=device-width, initial-scale=1'>";
  html += "<style>body{font-family:Arial;margin:20px;}";
  html += "a{display:block;padding:10px;margin:10px 0;background:#4CAF50;color:white;text-decoration:none;border-radius:5px;}";
  html += "a:hover{background:#45a049;}";
  html += "input,button{padding:10px;margin:5px;}</style></head><body>";
  html += "<h1>ESP32 GPS Tracker</h1>";
  html += "<a href='/stream'>View Live Feed</a>";
  html += "<a href='/sos_status'>SOS Status</a>";
  html += "<a href='/map'>Map View</a>";
  html += "<h3>Send Message to Display</h3>";
  html += "<form action='/send_message' method='POST'>";
  html += "<input type='text' name='message' placeholder='Enter message'>";
  html += "<button type='submit'>Send</button></form>";
  html += "</body></html>";
  server.send(200, "text/html", html);
}
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

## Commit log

2025-11-02 ESP32-CAM Code added
2025-11-06 ESP32 Cam code working added
2025-11-06 ESP32 cam working code added finally
2025-11-11 Nano Servo Code
2025-12-07 Update README with GuardianHat branding and add schematics PDF
    [Caretaker-B_Cu.gbr, Caretaker-B_Mask.gbr, Caretaker-B_Paste.gbr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]
2025-12-07 README.md updated
    [Caretaker 2.kicad_pcb, Caretaker 2.kicad_sch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]
